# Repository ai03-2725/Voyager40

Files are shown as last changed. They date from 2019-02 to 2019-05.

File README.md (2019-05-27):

# Voyager40
A compact, fully featured 40% PCB

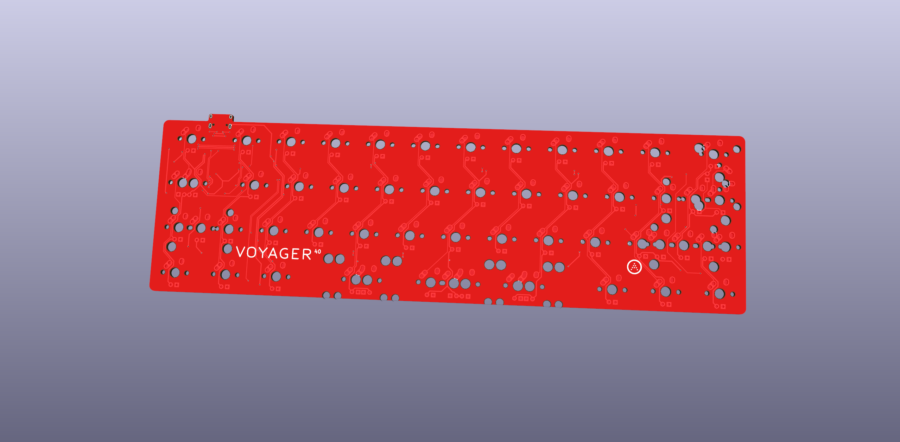
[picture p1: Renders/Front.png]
Render


[Supported layouts](http://www.keyboard-layout-editor.com/#/gists/b095690facf5e7ddff7d799d73baacf5)  

#### In light of recent claims that I am 100% liable for any of my open source PCBs, I am adding this disclaimer.
#### I provide these PCBs as a reference for designing keyboard PCBs. Using them within your projects will require a will to do research of one's own and to learn the workings of them, potentially fixing issues if they exist.
# I provide these PCBs without liability and without any guarantees regarding functionality, as expressed in the MIT license under which all of these PCBs are licensed.

### Features
* In-switch LED backlighting
* RGB underglow
* Decent amount of layout compatibility
* Over-current and static discharge protection
* Fully open-source

### The Voyager PCB Family
The Voyager PCBs offer fully featured PCBs fit for any keyboard, whether mass production or high-end.

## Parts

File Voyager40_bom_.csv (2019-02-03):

Component | Description | Part | References | Value | Footprint | Quantity Per PCB | Datasheet
1 | Unpolarized capacitor | C_Small | C3 C4 C5 | 0.1uF | C_0805 | 3
2 | Unpolarized capacitor | C_Small | C2 | 10uF | C_0805 | 1
3 | Unpolarized capacitor | C_Small | C6 | 1uF | C_0805 | 1
4 | Unpolarized capacitor | C_Small | C7 C8 | 22pF | C_0805 | 2
5 | Diode, small symbol | D_Small | D1 D2 D3 D4 D5 D6 D7 D8 D9 D10 D11 D12 D13 D14 D15 D16 D17 D18 D19 D20 D21 D22 D23 D24 D25 D26 D27 D28 D29 D30 D31 D32 D33 D34 D35 D36 D37 D38 D39 D40 D41 D42 D43 D44 D45 D46 D47 D48 D49 D50 D51 D52 D53 D54 D55 D56 D57 D58 D59 D60 D61 D62 D63 D64 D65 D66 | SOD-123 | D_SOD-123 | 66
6 | resettable fuse, polymeric positive temperature coefficient (PPTC), small symbol | Polyfuse_Small | F1 | 500mA | Fuse_SMD1206_Reflow | 1
7 | Transistor NPN (general) | Q_NPN_BEC | Q1 | MMBT2222ALT3G | SOT-23 | 1
8 | Resistor, small symbol | R_Small | R70 | 10k | R_0805 | 1
9 | Resistor, small symbol | R_Small | R1 R2 R3 R4 R5 R6 R7 R8 R9 R10 R11 R12 R13 R14 R15 R16 R17 R18 R19 R20 R21 R22 R23 R24 R25 R26 R27 R28 R29 R30 R31 R32 R33 R34 R35 R36 R37 R38 R39 R40 R41 R42 R43 R44 R45 R46 R47 R48 R49 R50 R51 R52 R53 R54 R55 R56 R57 R58 R59 R60 R61 R62 R63 R64 R65 R66 R69 R71 | 1k | R_0805 | 68
10 | Resistor, small symbol | R_Small | R67 R68 | 22 | R_0805 | 2
11 | Push button switch, generic, two pins | SW_Push | SW1 | SKQG-1155865 | SKQG-1155865 | 1
12 |  | ATmega32U4 | U1 | ATmega32U4 | TQFP-44_10x10mm_Pitch0.8mm | 1
13 |  | Molex-0548190589 | USB1 | Molex-0548190589 | Molex-0548190589 | 1
14 | Four pin crystal (GND on pins 2 and 4), e.g. in SMD package | Crystal_GND24 | Y1 | 16Mhz | Crystal_SMD_3225-4pin_3.2x2.5mm_HandSoldering | 1
Component Groups: | 14
Component Count: | 150
Fitted Components: | 150
Number of PCBs: | 1
Total components: | 150
Schematic Version:
Schematic Date:
BoM Date: | 6/27/2018 22:00
Schematic Source: | C:/Users/Ryota/Documents/GitHub/03Mini-EX/03Mini-EX.sch
KiCad Version: | Eeschema 4.0.7

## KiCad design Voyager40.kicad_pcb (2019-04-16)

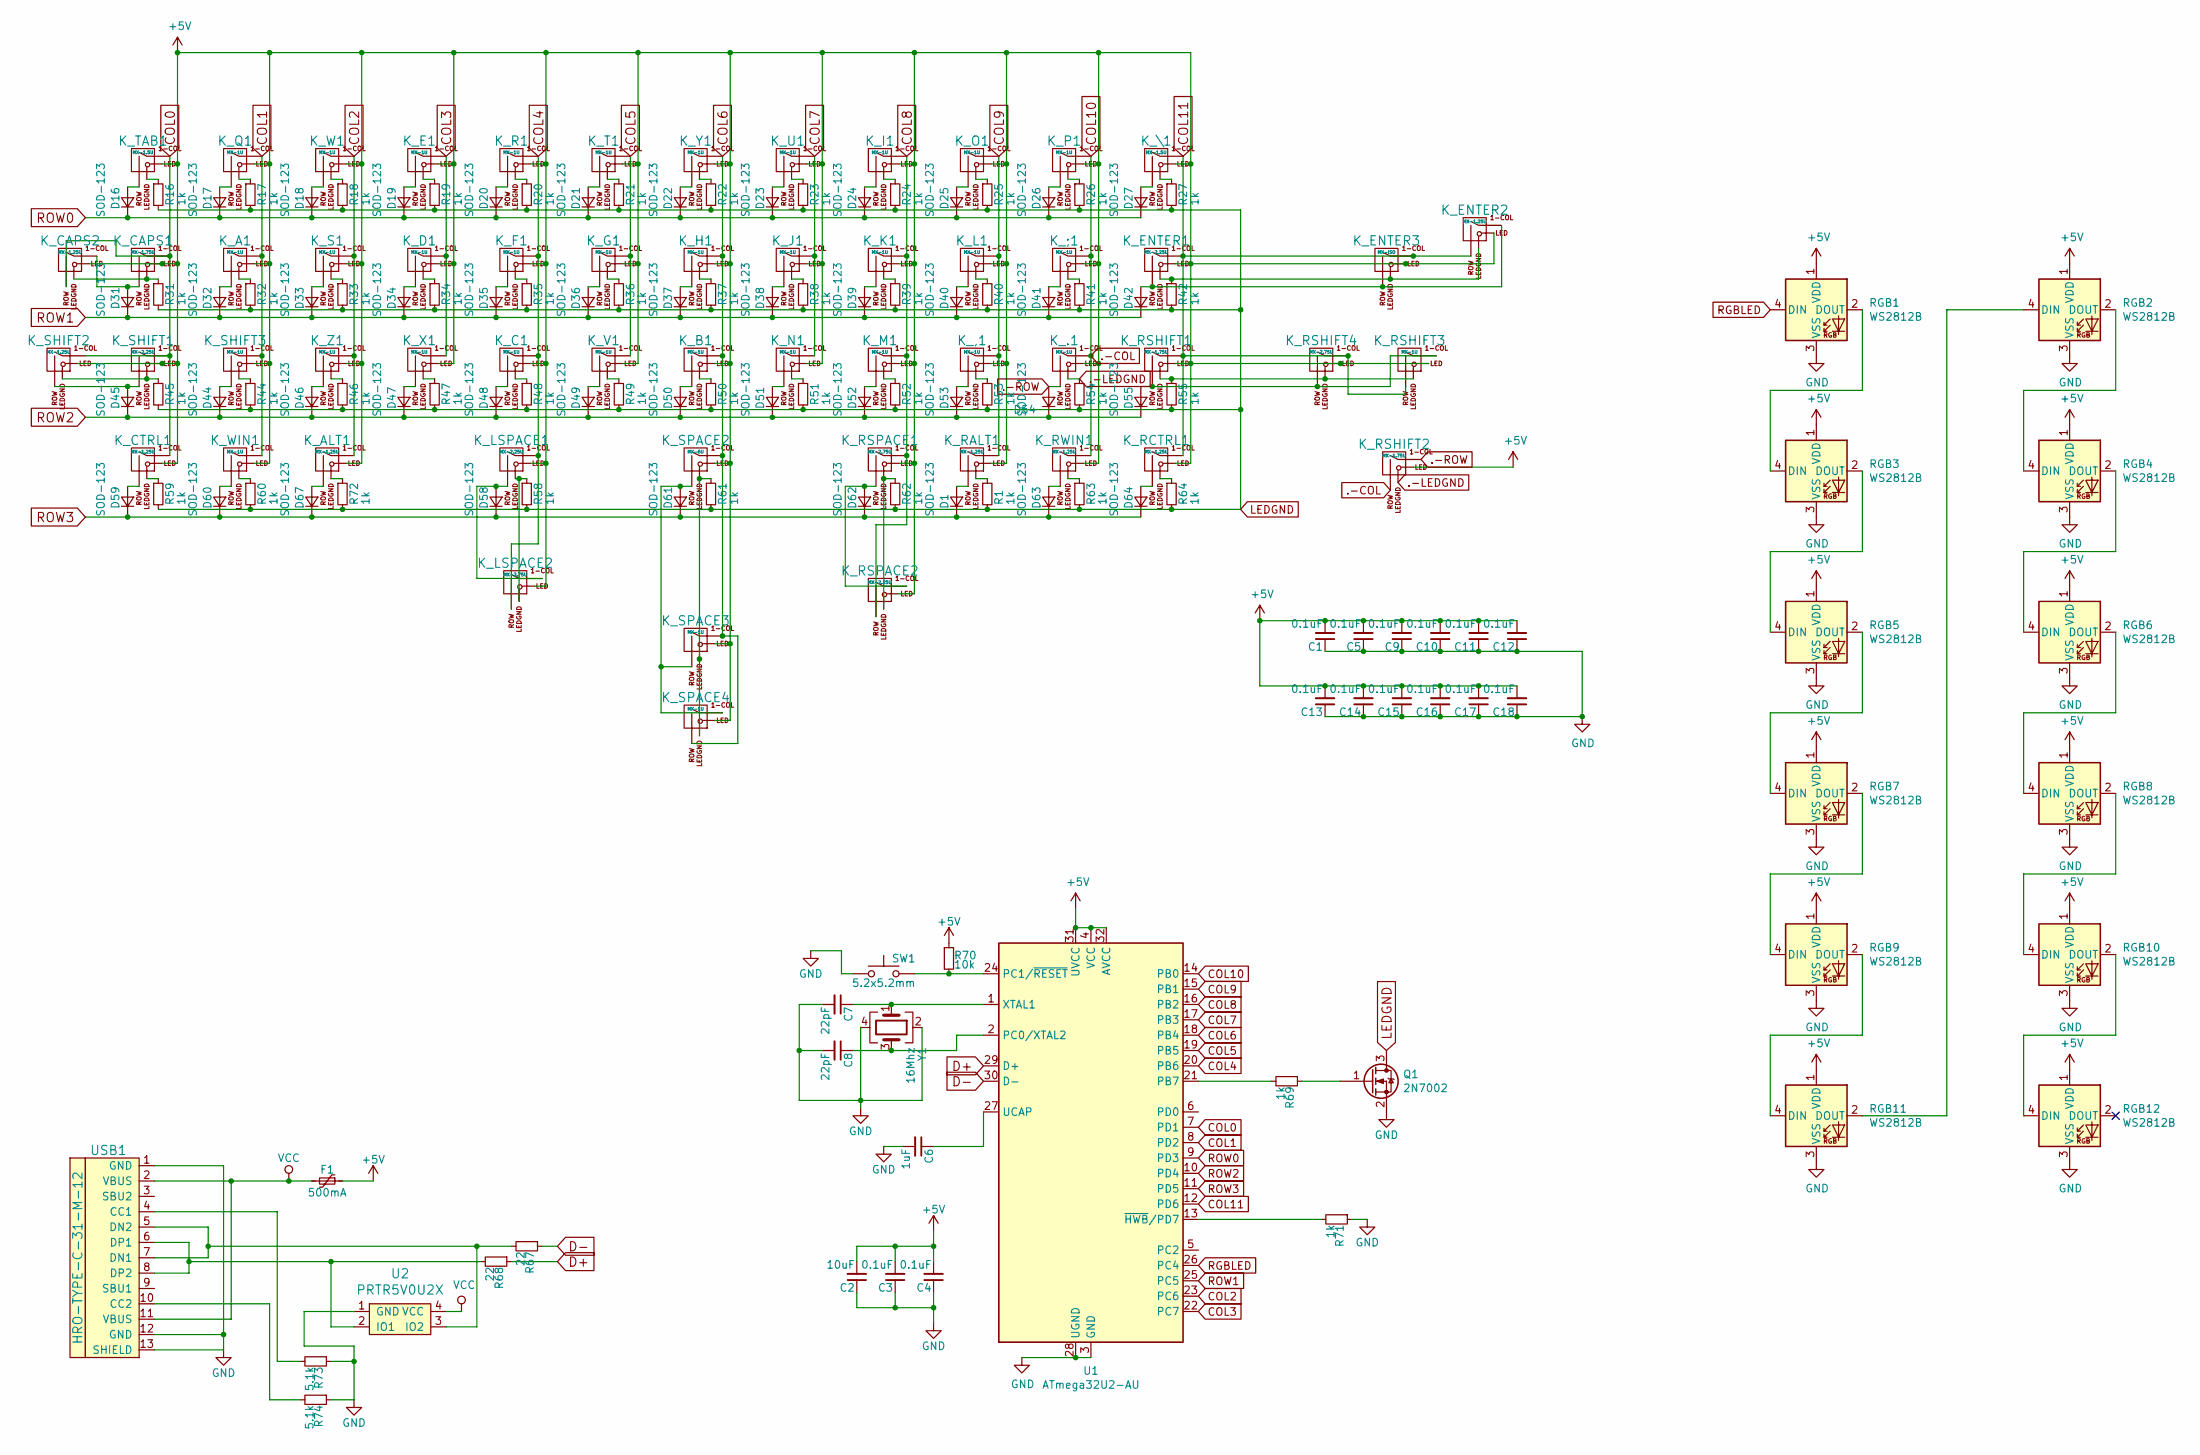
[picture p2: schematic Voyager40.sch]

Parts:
C1, C3, C4, C5, C9, C10, C11, C12, C13, C14, C15, C16, C17, C18: 0.1uF; C_0603
C2: 10uF; C_0603
C6: 1uF; C_0603
C7, C8: 22pF; C_0603
D1, D16, D17, D18, D19, D20, D21, D22, D23, D24, D25, D26, D27, D31, D32, D33, D34, D35, D36, D37, D38, D39, D40, D41, D42, D44, D45, D46, D47, D48, D49, D50, D51, D52, D53, D54, D55, D58, D59, D60, D61, D62, D63, D64, D67: SOD-123; D_SOD-123
F1: 500mA; Fuse_SMD1206_Reflow
K_,1: MX-1U
K_.1: MX-1U
K_;1: MX-1U
K_A1: MX-1U
K_ALT1: MX-1.25U
K_B1: MX-1U
K_C1: MX-1U
K_CAPS1: MX-1.75U
K_CAPS2: MX-1.25U; MX-1.25U-FLIPPED
K_CTRL1: MX-1.25U
K_D1: MX-1U
K_E1: MX-1U
K_ENTER1: MX-2.25U
K_ENTER2: MX-1.25U
K_ENTER3: MX-ISO; MX-ISO-ReversedStabilizers
K_F1: MX-1U
K_G1: MX-1U
K_H1: MX-1U
K_I1: MX-1U
K_J1: MX-1U
K_K1: MX-1U
K_L1: MX-1U
K_LSPACE1: MX-2.25U; MX-2.25U-ReversedStabilizers
K_LSPACE2: MX-2.75U; MX-2.75U-FLIPPED-ReversedStabilizers
K_M1: MX-1U
K_N1: MX-1U
K_O1: MX-1U
K_P1: MX-1U
K_Q1: MX-1U
K_R1: MX-1U
K_RALT1: MX-1.25U
K_RCTRL1: MX-1.25U
K_RSHIFT1, K_RSHIFT2: MX-1.75U
K_RSHIFT3: MX-1U
K_RSHIFT4: MX-2.75U
K_RSPACE1: MX-2.75U; MX-2.75U-ReversedStabilizers
K_RSPACE2: MX-2.25U; MX-2.25U-FLIPPED-ReversedStabilizers
K_RWIN1: MX-1.25U; MX-1U
K_S1: MX-1U
K_SHIFT1: MX-2.25U
K_SHIFT2: MX-1.25U
K_SHIFT3: MX-1U
K_SPACE2: MX-6U; MX-6U-ReversedStabilizers
K_SPACE3: MX-1U
K_SPACE4: MX-1U; MX-1U-FLIPPED
K_T1: MX-1U
K_TAB1: MX-1.5U
K_U1: MX-1U
K_V1: MX-1U
K_W1: MX-1U
K_WIN1: MX-1U
K_X1: MX-1U
K_Y1: MX-1U
K_Z1: MX-1U
K_\1: MX-1.5U
Q1: 2N7002; SOT-23
R1, R16, R17, R18, R19, R20, R21, R22, R23, R24, R25, R26, R27, R31, R32, R33, R34, R35, R36, R37, R38, R39, R40, R41, R42, R44, R45, R46, R47, R48, R49, R50, R51, R52, R53, R54, R55, R58, R59, R60, R61, R62, R63, R64, R69, R71, R72: 1k; R_0805
R67, R68: 22; R_0805
R70: 10k; R_0805
R73, R74: 5.1k; R_0805
RGB1, RGB2, RGB3, RGB4, RGB5, RGB6, RGB7, RGB8, RGB9, RGB10, RGB11, RGB12: WS2812B; LED_WS2812B-PLCC4
SW1: 5.2x5.2mm; SKQGADE010
U1: ATmega32U2-AU; QFN-32-1EP_5x5mm_Pitch0.5mm
U2: PRTR5V0U2X; SOT143B
USB1: HRO-TYPE-C-31-M-12; HRO-TYPE-C-31-M-12-Assembly
Y1: 16Mhz; Crystal_SMD_3225-4pin_3.2x2.5mm

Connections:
+5V: C1.2, C2.2, C3.2, C4.2, C5.2, C9.2, C10.2, C11.2, C12.2, C13.2, C14.2, C15.2, C16.2, C17.2, C18.2, F1.1, K_,1.3 (LED), K_.1.3 (LED), K_;1.3 (LED), K_A1.3 (LED), K_ALT1.3 (LED), K_B1.3 (LED), K_C1.3 (LED), K_CAPS1.3 (LED), K_CAPS2.3 (LED), K_CTRL1.3 (LED), K_D1.3 (LED), K_E1.3 (LED), K_ENTER1.3 (LED), K_ENTER2.3 (LED), K_ENTER3.3 (LED), K_F1.3 (LED), K_G1.3 (LED), K_H1.3 (LED), K_I1.3 (LED), K_J1.3 (LED), K_K1.3 (LED), K_L1.3 (LED), K_LSPACE1.3 (LED), K_LSPACE2.3 (LED), K_M1.3 (LED), K_N1.3 (LED), K_O1.3 (LED), K_P1.3 (LED), K_Q1.3 (LED), K_R1.3 (LED), K_RALT1.3 (LED), K_RCTRL1.3 (LED), K_RSHIFT1.3 (LED), K_RSHIFT2.3 (LED), K_RSHIFT3.3 (LED), K_RSHIFT4.3 (LED), K_RSPACE1.3 (LED), K_RSPACE2.3 (LED), K_RWIN1.3 (LED), K_S1.3 (LED), K_SHIFT1.3 (LED), K_SHIFT2.3 (LED), K_SHIFT3.3 (LED), K_SPACE2.3 (LED), K_SPACE3.3 (LED), K_SPACE4.3 (LED), K_T1.3 (LED), K_TAB1.3 (LED), K_U1.3 (LED), K_V1.3 (LED), K_W1.3 (LED), K_WIN1.3 (LED), K_X1.3 (LED), K_Y1.3 (LED), K_Z1.3 (LED), K_\1.3 (LED), R70.1, RGB1.1 (VDD), RGB2.1 (VDD), RGB3.1 (VDD), RGB4.1 (VDD), RGB5.1 (VDD), RGB6.1 (VDD), RGB7.1 (VDD), RGB8.1 (VDD), RGB9.1 (VDD), RGB10.1 (VDD), RGB11.1 (VDD), RGB12.1 (VDD), U1.4 (VCC), U1.31 (UVCC), U1.32 (AVCC)
.-COL: K_.1.1 (COL), K_;1.1 (COL), K_P1.1 (COL), K_RSHIFT2.2 (ROW), K_RWIN1.1 (COL), U1.14 (PB0)
.-LEDGND: K_.1.4 (LEDGND), K_RSHIFT2.4 (LEDGND), R54.1
.-ROW: D54.2 (A), K_.1.2 (ROW), K_RSHIFT2.1 (COL)
COL0: K_CAPS1.1 (COL), K_CAPS2.2 (ROW), K_CTRL1.1 (COL), K_SHIFT1.1 (COL), K_SHIFT2.1 (COL), K_TAB1.1 (COL), U1.7 (PD1)
COL1: K_A1.1 (COL), K_Q1.1 (COL), K_SHIFT3.1 (COL), K_WIN1.1 (COL), U1.8 (PD2)
COL2: K_ALT1.1 (COL), K_S1.1 (COL), K_W1.1 (COL), K_Z1.1 (COL), U1.23 (PC6)
COL3: K_D1.1 (COL), K_E1.1 (COL), K_X1.1 (COL), U1.22 (PC7)
COL4: K_C1.1 (COL), K_F1.1 (COL), K_LSPACE1.1 (COL), K_LSPACE2.2 (ROW), K_R1.1 (COL), U1.20 (PB6)
COL5: K_G1.1 (COL), K_T1.1 (COL), K_V1.1 (COL), U1.19 (PB5)
COL6: K_B1.1 (COL), K_H1.1 (COL), K_SPACE2.1 (COL), K_SPACE3.1 (COL), K_SPACE4.2 (ROW), K_Y1.1 (COL), U1.18 (PB4)
COL7: K_J1.1 (COL), K_N1.1 (COL), K_U1.1 (COL), U1.17 (PB3)
COL8: K_I1.1 (COL), K_K1.1 (COL), K_M1.1 (COL), K_RSPACE1.1 (COL), K_RSPACE2.2 (ROW), U1.16 (PB2)
COL9: K_,1.1 (COL), K_L1.1 (COL), K_O1.1 (COL), K_RALT1.1 (COL), U1.15 (PB1)
COL11: K_ENTER1.1 (COL), K_ENTER2.2 (ROW), K_ENTER3.1 (COL), K_RCTRL1.1 (COL), K_RSHIFT1.1 (COL), K_RSHIFT3.2 (ROW), K_RSHIFT4.1 (COL), K_\1.1 (COL), U1.12 (PD6)
D+: R68.1, U1.29 (D+)
D-: R67.1, U1.30 (D-)
GND: C1.1, C2.1, C3.1, C4.1, C5.1, C6.2, C7.2, C8.2, C9.1, C10.1, C11.1, C12.1, C13.1, C14.1, C15.1, C16.1, C17.1, C18.1, Q1.2 (S), R71.1, R73.1, R74.1, RGB1.3 (VSS), RGB2.3 (VSS), RGB3.3 (VSS), RGB4.3 (VSS), RGB5.3 (VSS), RGB6.3 (VSS), RGB7.3 (VSS), RGB8.3 (VSS), RGB9.3 (VSS), RGB10.3 (VSS), RGB11.3 (VSS), RGB12.3 (VSS), SW1.1, U1.3 (GND), U1.28 (UGND), U2.1 (GND), USB1.1 (GND), USB1.12 (GND), USB1.13 (SHIELD), Y1.2, Y1.4
LEDGND: Q1.3 (D), R1.2, R16.2, R17.2, R18.2, R19.2, R20.2, R21.2, R22.2, R23.2, R24.2, R25.2, R26.2, R27.2, R31.2, R32.2, R33.2, R34.2, R35.2, R36.2, R37.2, R38.2, R39.2, R40.2, R41.2, R42.2, R44.2, R45.2, R46.2, R47.2, R48.2, R49.2, R50.2, R51.2, R52.2, R53.2, R54.2, R55.2, R58.2, R59.2, R60.2, R61.2, R62.2, R63.2, R64.2, R72.2
unnamed: C6.1, U1.27 (UCAP)
unnamed: C7.1, U1.1 (XTAL1), Y1.1
unnamed: C8.1, U1.2 (PC0/XTAL2), Y1.3
unnamed: D1.2 (A), K_RALT1.2 (ROW)
unnamed: D16.2 (A), K_TAB1.2 (ROW)
unnamed: D17.2 (A), K_Q1.2 (ROW)
unnamed: D18.2 (A), K_W1.2 (ROW)
unnamed: D19.2 (A), K_E1.2 (ROW)
unnamed: D20.2 (A), K_R1.2 (ROW)
unnamed: D21.2 (A), K_T1.2 (ROW)
unnamed: D22.2 (A), K_Y1.2 (ROW)
unnamed: D23.2 (A), K_U1.2 (ROW)
unnamed: D24.2 (A), K_I1.2 (ROW)
unnamed: D25.2 (A), K_O1.2 (ROW)
unnamed: D26.2 (A), K_P1.2 (ROW)
unnamed: D27.2 (A), K_\1.2 (ROW)
unnamed: D31.2 (A), K_CAPS1.2 (ROW), K_CAPS2.1 (COL)
unnamed: D32.2 (A), K_A1.2 (ROW)
unnamed: D33.2 (A), K_S1.2 (ROW)
unnamed: D34.2 (A), K_D1.2 (ROW)
unnamed: D35.2 (A), K_F1.2 (ROW)
unnamed: D36.2 (A), K_G1.2 (ROW)
unnamed: D37.2 (A), K_H1.2 (ROW)
unnamed: D38.2 (A), K_J1.2 (ROW)
unnamed: D39.2 (A), K_K1.2 (ROW)
unnamed: D40.2 (A), K_L1.2 (ROW)
unnamed: D41.2 (A), K_;1.2 (ROW)
unnamed: D42.2 (A), K_ENTER1.2 (ROW), K_ENTER2.1 (COL), K_ENTER3.2 (ROW)
unnamed: D44.2 (A), K_SHIFT3.2 (ROW)
unnamed: D45.2 (A), K_SHIFT1.2 (ROW), K_SHIFT2.2 (ROW)
unnamed: D46.2 (A), K_Z1.2 (ROW)
unnamed: D47.2 (A), K_X1.2 (ROW)
unnamed: D48.2 (A), K_C1.2 (ROW)
unnamed: D49.2 (A), K_V1.2 (ROW)
unnamed: D50.2 (A), K_B1.2 (ROW)
unnamed: D51.2 (A), K_N1.2 (ROW)
unnamed: D52.2 (A), K_M1.2 (ROW)
unnamed: D53.2 (A), K_,1.2 (ROW)
unnamed: D55.2 (A), K_RSHIFT1.2 (ROW), K_RSHIFT3.1 (COL), K_RSHIFT4.2 (ROW)
unnamed: D58.2 (A), K_LSPACE1.2 (ROW), K_LSPACE2.1 (COL)
unnamed: D59.2 (A), K_CTRL1.2 (ROW)
unnamed: D60.2 (A), K_WIN1.2 (ROW)
unnamed: D61.2 (A), K_SPACE2.2 (ROW), K_SPACE3.2 (ROW), K_SPACE4.1 (COL)
unnamed: D62.2 (A), K_RSPACE1.2 (ROW), K_RSPACE2.1 (COL)
unnamed: D63.2 (A), K_RWIN1.2 (ROW)
unnamed: D64.2 (A), K_RCTRL1.2 (ROW)
unnamed: D67.2 (A), K_ALT1.2 (ROW)
unnamed: K_,1.4 (LEDGND), R53.1
unnamed: K_;1.4 (LEDGND), R41.1
unnamed: K_A1.4 (LEDGND), R32.1
unnamed: K_ALT1.4 (LEDGND), R72.1
unnamed: K_B1.4 (LEDGND), R50.1
unnamed: K_C1.4 (LEDGND), R48.1
unnamed: K_CAPS1.4 (LEDGND), K_CAPS2.4 (LEDGND), R31.1
unnamed: K_CTRL1.4 (LEDGND), R59.1
unnamed: K_D1.4 (LEDGND), R34.1
unnamed: K_E1.4 (LEDGND), R19.1
unnamed: K_ENTER1.4 (LEDGND), K_ENTER2.4 (LEDGND), K_ENTER3.4 (LEDGND), R42.1
unnamed: K_F1.4 (LEDGND), R35.1
unnamed: K_G1.4 (LEDGND), R36.1
unnamed: K_H1.4 (LEDGND), R37.1
unnamed: K_I1.4 (LEDGND), R24.1
unnamed: K_J1.4 (LEDGND), R38.1
unnamed: K_K1.4 (LEDGND), R39.1
unnamed: K_L1.4 (LEDGND), R40.1
unnamed: K_LSPACE1.4 (LEDGND), K_LSPACE2.4 (LEDGND), R58.1
unnamed: K_M1.4 (LEDGND), R52.1
unnamed: K_N1.4 (LEDGND), R51.1
unnamed: K_O1.4 (LEDGND), R25.1
unnamed: K_P1.4 (LEDGND), R26.1
unnamed: K_Q1.4 (LEDGND), R17.1
unnamed: K_R1.4 (LEDGND), R20.1
unnamed: K_RALT1.4 (LEDGND), R1.1
unnamed: K_RCTRL1.4 (LEDGND), R64.1
unnamed: K_RSHIFT1.4 (LEDGND), K_RSHIFT3.4 (LEDGND), K_RSHIFT4.4 (LEDGND), R55.1
unnamed: K_RSPACE1.4 (LEDGND), K_RSPACE2.4 (LEDGND), R62.1
unnamed: K_RWIN1.4 (LEDGND), R63.1
unnamed: K_S1.4 (LEDGND), R33.1
unnamed: K_SHIFT1.4 (LEDGND), K_SHIFT2.4 (LEDGND), R45.1
unnamed: K_SHIFT3.4 (LEDGND), R44.1
unnamed: K_SPACE2.4 (LEDGND), K_SPACE3.4 (LEDGND), K_SPACE4.4 (LEDGND), R61.1
unnamed: K_T1.4 (LEDGND), R21.1
unnamed: K_TAB1.4 (LEDGND), R16.1
unnamed: K_U1.4 (LEDGND), R23.1
unnamed: K_V1.4 (LEDGND), R49.1
unnamed: K_W1.4 (LEDGND), R18.1
unnamed: K_WIN1.4 (LEDGND), R60.1
unnamed: K_X1.4 (LEDGND), R47.1
unnamed: K_Y1.4 (LEDGND), R22.1
unnamed: K_Z1.4 (LEDGND), R46.1
unnamed: K_\1.4 (LEDGND), R27.1
unnamed: Q1.1 (G), R69.1
unnamed: R67.2, U2.3 (IO2), USB1.5 (DN2), USB1.7 (DN1)
unnamed: R68.2, U2.2 (IO1), USB1.6 (DP1), USB1.8 (DP2)
unnamed: R69.2, U1.21 (PB7)
unnamed: R70.2, SW1.2, U1.24 (PC1/~RESET)
unnamed: R71.2, U1.13 (~HWB~/PD7)
unnamed: R73.2, USB1.4 (CC1)
unnamed: R74.2, USB1.10 (CC2)
unnamed: RGB1.2 (DOUT), RGB3.4 (DIN)
unnamed: RGB2.2 (DOUT), RGB4.4 (DIN)
unnamed: RGB3.2 (DOUT), RGB5.4 (DIN)
unnamed: RGB4.2 (DOUT), RGB6.4 (DIN)
unnamed: RGB5.2 (DOUT), RGB7.4 (DIN)
unnamed: RGB6.2 (DOUT), RGB8.4 (DIN)
unnamed: RGB7.2 (DOUT), RGB9.4 (DIN)
unnamed: RGB10.2 (DOUT), RGB12.4 (DIN)
unnamed: RGB8.2 (DOUT), RGB10.4 (DIN)
unnamed: RGB2.4 (DIN), RGB11.2 (DOUT)
unnamed: RGB9.2 (DOUT), RGB11.4 (DIN)
RGBLED: RGB1.4 (DIN), U1.26 (PC4)
ROW0: D16.1 (K), D17.1 (K), D18.1 (K), D19.1 (K), D20.1 (K), D21.1 (K), D22.1 (K), D23.1 (K), D24.1 (K), D25.1 (K), D26.1 (K), D27.1 (K), U1.9 (PD3)
ROW1: D31.1 (K), D32.1 (K), D33.1 (K), D34.1 (K), D35.1 (K), D36.1 (K), D37.1 (K), D38.1 (K), D39.1 (K), D40.1 (K), D41.1 (K), D42.1 (K), U1.25 (PC5)
ROW2: D44.1 (K), D45.1 (K), D46.1 (K), D47.1 (K), D48.1 (K), D49.1 (K), D50.1 (K), D51.1 (K), D52.1 (K), D53.1 (K), D54.1 (K), D55.1 (K), U1.10 (PD4)
ROW3: D1.1 (K), D58.1 (K), D59.1 (K), D60.1 (K), D61.1 (K), D62.1 (K), D63.1 (K), D64.1 (K), D67.1 (K), U1.11 (PD5)
VCC: F1.2, U2.4 (VCC), USB1.2 (VBUS), USB1.11 (VBUS)

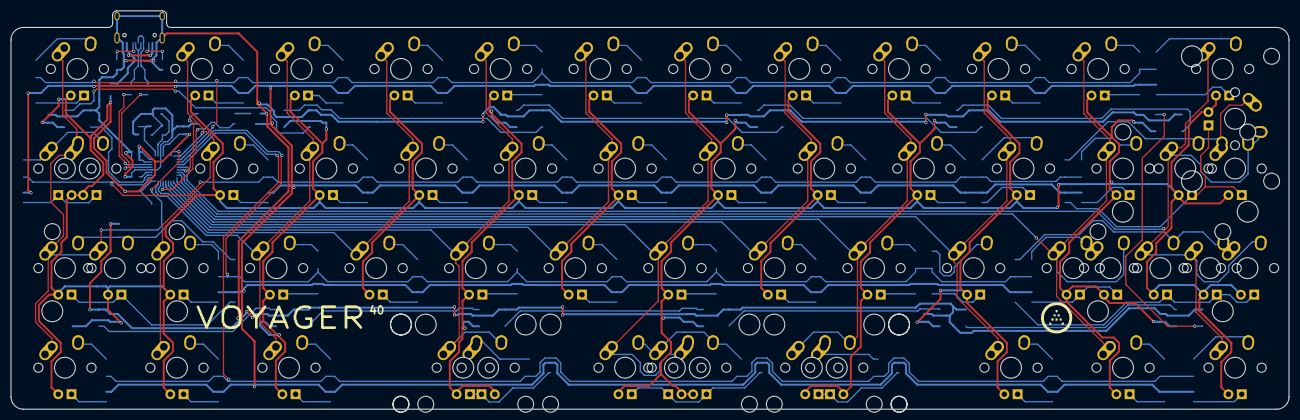
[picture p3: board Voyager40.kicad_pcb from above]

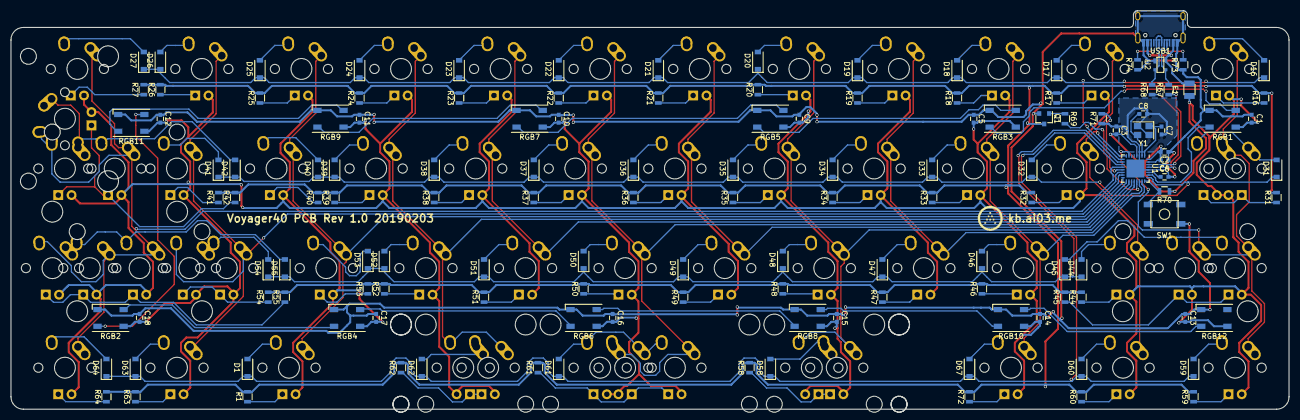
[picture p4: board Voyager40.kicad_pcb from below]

Board: 2 copper layers, 244.5 x 76.2 mm, 190 parts (134 on the bottom side), 135 nets.

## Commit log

2019-02-03 Finish up project
    [Voyager40-B.Cu.gbl, Voyager40-B.Fab.gbr, Voyager40-B.Mask.gbs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]
2019-04-16 Repair the column traces
    [Voyager40-B.Cu.gbl, Voyager40-B.Fab.gbr, Voyager40-B.Mask.gbs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]
